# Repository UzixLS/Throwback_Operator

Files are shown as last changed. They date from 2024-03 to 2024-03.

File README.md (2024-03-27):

# THROWBACK OPERATOR
OPL3 VGM player powered by STM32

This project is a hardware video game music (VGM) player that uses a genuine YMF262 (OPL3) sound chip and its accompanying YAC512 DAC.
There is no emulation here. This is the real chip.

Included in this repository is the complete schematic, firmware source, and KiCAD board files. Feel free to make your own board, but please don't resell them :)

If you would like to purchase an official complete Throwback Operator board, you can order one from me here: https://www.aidanlawrence.com/product/throwback-operator/

# Information About the Main Sound Chips and VGM

The YMF262, also known as the Operator Type L3 (OPL3), is an 18-channel FM sound chip that was commonly found inside of personal computers in the mid to late 1990's.
Most notably, the OPL3 was found on the Sound Blaster Pro 2 and the Sound Blaster 16.
The OPL3 is backwards compatible with the OPL2 (YM3812). The OPL2 is backwards compatible with the original OPL (YM3526).
This means that the Throwback Operator is capable of playing back OPL3, OPL2, and OPL tracks. The OPL2 was found on the original Adlib and Sound Blaster cards.
The OPL was usually found within arcade machines.

The clock signal for the YMF262 is dynamically generated from the microcontroller. The timers on this particular board only have 16-bit resolution, so VGMs with exotic frequencies may not sound perfectly in tune. Standard clock OPL2 and OPL3 VGMs will often sound just fine though.

VGM stands for Video Game Music, and it is a 44.1KHz logging format that stores real sound chip register information. My player will parse these files and send the data to the appropriate chips. You can learn more about the VGM file format here: http://www.smspower.org/Music/VGMFileFormat

http://www.smspower.org/uploads/Music/vgmspec170.txt?sid=58da937e68300c059412b536d4db2ca0

# Schematic
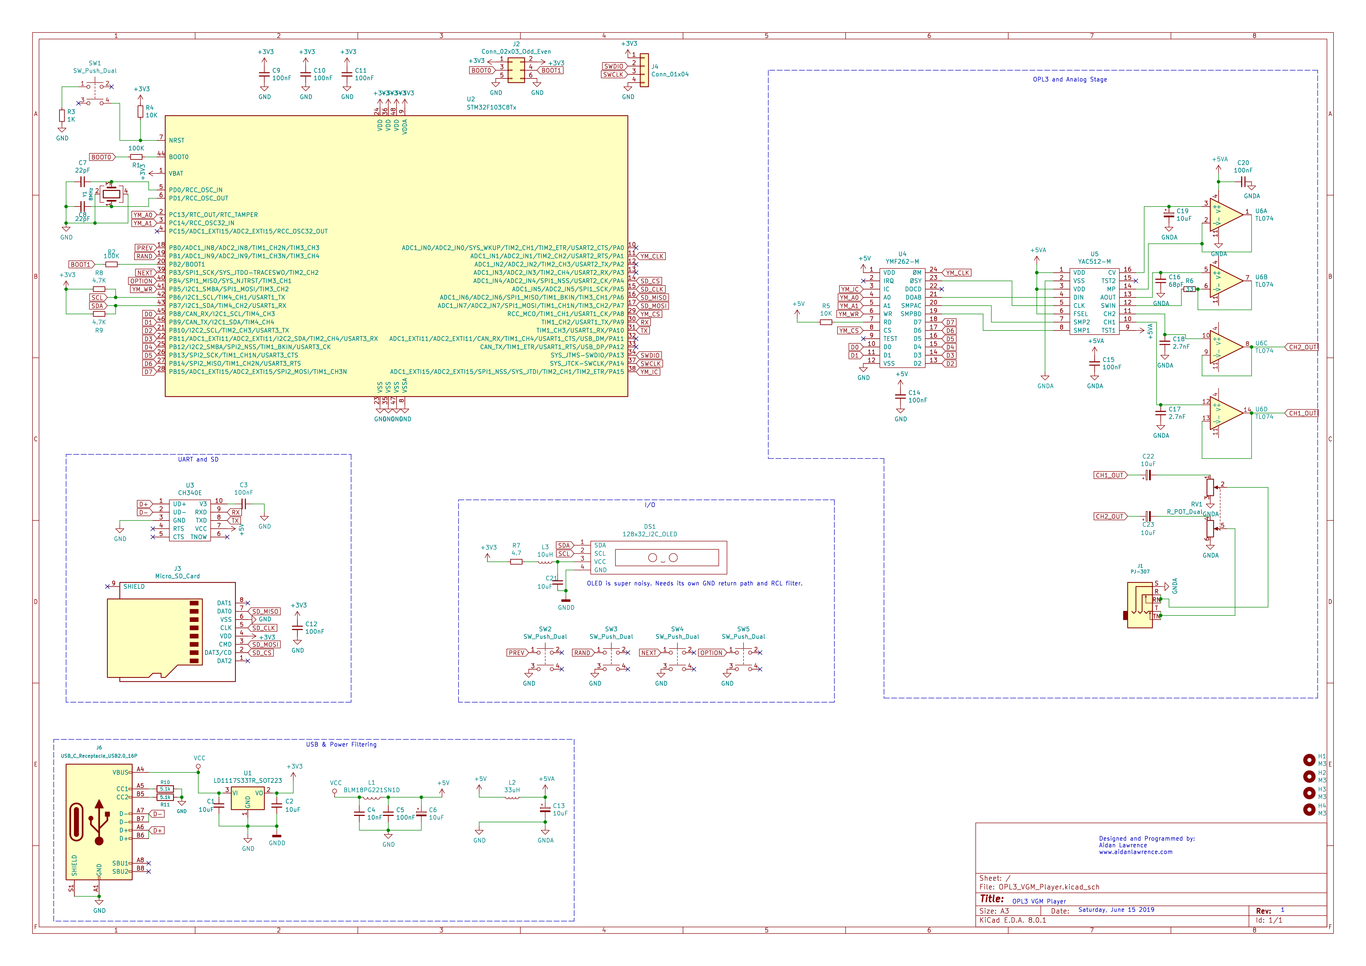
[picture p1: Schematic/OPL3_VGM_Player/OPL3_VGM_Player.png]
Schematic


# SD Card Information

The Throwback Operator accepts MicroSD cards formatted as FAT32. Your SD card must only contain uncompressed .vgm files. VGZ FILES WILL NOT WORK! You may download .vgz files and use 7zip to extract the uncompressed file out of them. Vgm files on the SD card do not need to have the .vgm extension. As long as they contain valid, uncompressed vgm data, they will be read by the program regardless of their name. You can find VGM files by Googling "myGameName VGM," or by checking out sites like http://vgmrips.net/packs/

# Control Over Serial
You can use a serial connection to control playback features. The commands are as follows:

Command | Result
------------ | -------------
\+ | Next Track
\- | Previous Track
\* | Random Track
\/ | Toggle Shuffle Mode
\. | Toggle Song Looping
r: | Request song
? | What song is playing?
\! | Toggle the OLED display

A song request is formatted as follows: ```r:mySongFile.vgm```
Once a song request is sent through the serial console, an attempt will be made to open that song file. The file must exist on the SD card, and spelling/capitalization must be correct.
Need an easy-to-use serial console? [I've made one here.](https://github.com/AidanHockey5/OpenArduinoSerialConsole)

# Programming the Microcontroller

The on-board microcontroller is a STM32F103C8T6, the same microcontroller found on the popular "blue pill" development boards. 
Therefore, programming the Throwback Operator boards is fairly similar.
The firmware was built with Visual Studio Code with the PlatformIO extension installed.

Programming over Serial:
* Connect your Throwback Operator board to your computers USB port.
* Ensure that you have the CH340 driver installed. Windows 10 should have this automatically, otherwise, [grab the driver here](https://sparks.gogo.co.nz/ch340.html)
* Ensure nothing else is currently connected to your board over serial.
* On the top of the board, you will see two black jumpers. By default, these jumpers are both in the "Down" position (middle pin and bottom pin jumped).
* Remove the left jumper and reattach it to the "Up" position (middle pin and top pin jumped).
* Press the RESET button on the Throwback Operator board

* You can either program the device with the flashing tool linked below, or from the source code.

[DOWNLOAD THE FLASHING TOOL HERE](https://www.aidanlawrence.com/tools/ee/tbo/Megaflasher_Throwback_Operator.zip)

* Windows users are reccomended to run the pre-compiled "Flash.exe" file.
  All other operating system users must run the Flash.py file. 
  Dependancies and instructions are listed in the Readme file.
* After successfully running the flashing tool, you are done and don't need to continue with the following instructions.

If you plan to build from the source code instead:
* In VS Code (or whatever your IDE of choice is), navigate to the `platformio.ini` and ensure the upload protocol is set to `serial`
* Hit the upload button (Arrow icon in the bottom bar of VS code)
* Once your code is uploaded, replace the left jumper to its original "Down" position 

# Troubleshooting

Occasionally, when the player is first plugged in, it will hang or get caught in a boot-loop. Plugging in a USB cable gives breif moments of unstable power when the contacts inside of the connector are jostling against eachother which may place the SD card in an unknown state. Simply disconnect and reconnect the USB cable if you are caught in a bootloop.

This player is for OPL-family VGMs only. That means you can play any VGM file that contains data for the YM3526 (OPL), YM3812 (OPL2) or the YMF262 (OPL3).

Ensure that your VGM files are uncompressed. VGZ files will not work. Simply use 7zip on VGM files to extract the VGM files within.

Make sure your SD card is formatted to FAT32 and only contains VGM files. Folders are not supported.

# Looking for an Enclosure for your Player?

Voodle has contributed a 3D-printable enclosure for the Throwback Operator!
https://www.thingiverse.com/thing:4577831

Thanks, Voodle!

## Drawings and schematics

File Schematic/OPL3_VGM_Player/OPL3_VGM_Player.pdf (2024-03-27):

# 100nF ⁺³V³

# +5VA GNDA

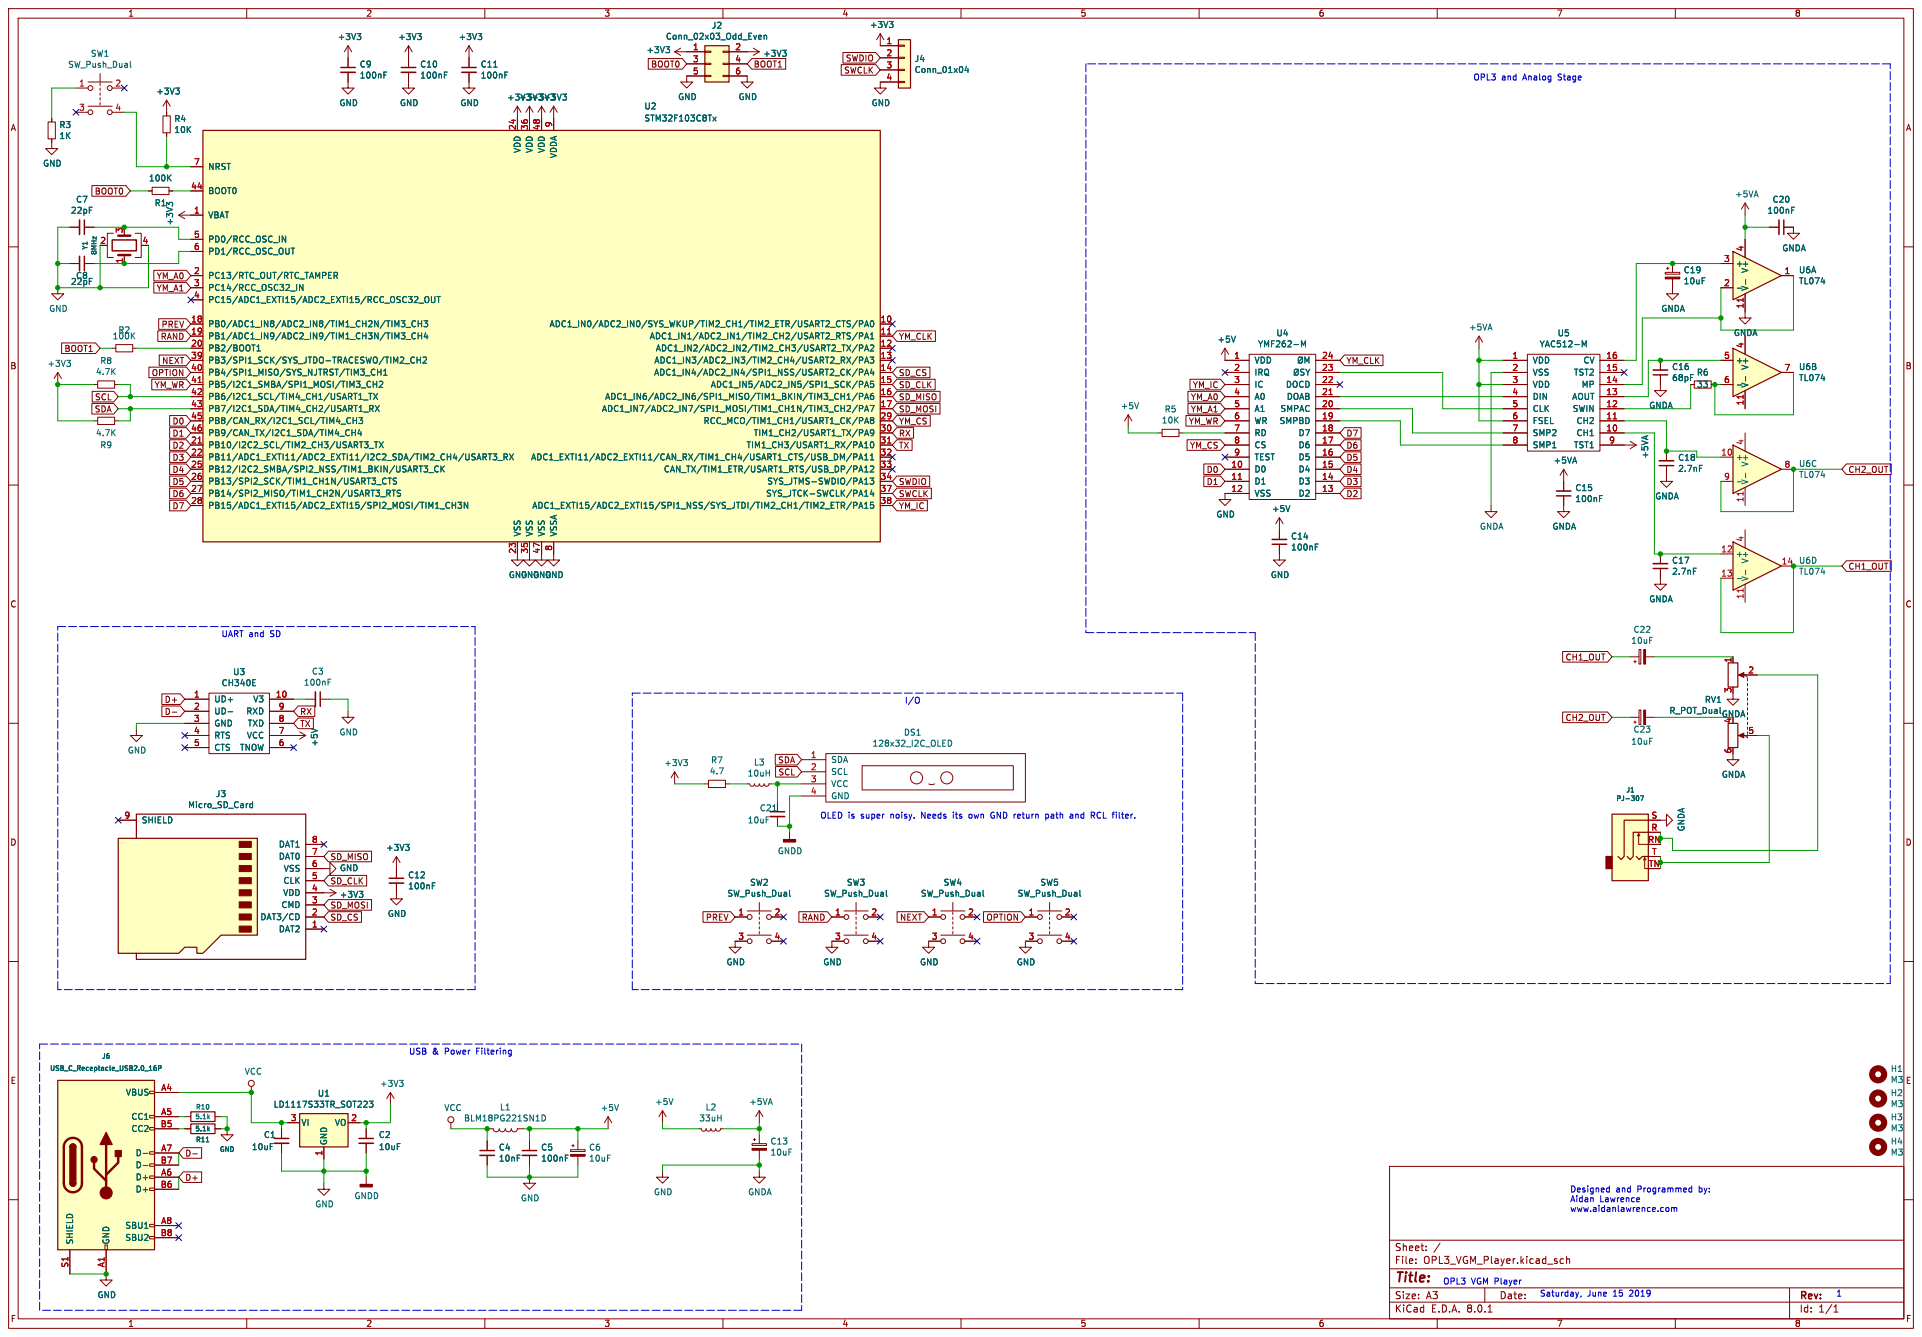
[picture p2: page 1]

Id: 1/1 Title: File: OPL3_VGM_Player.kicad_sch Sheet: /

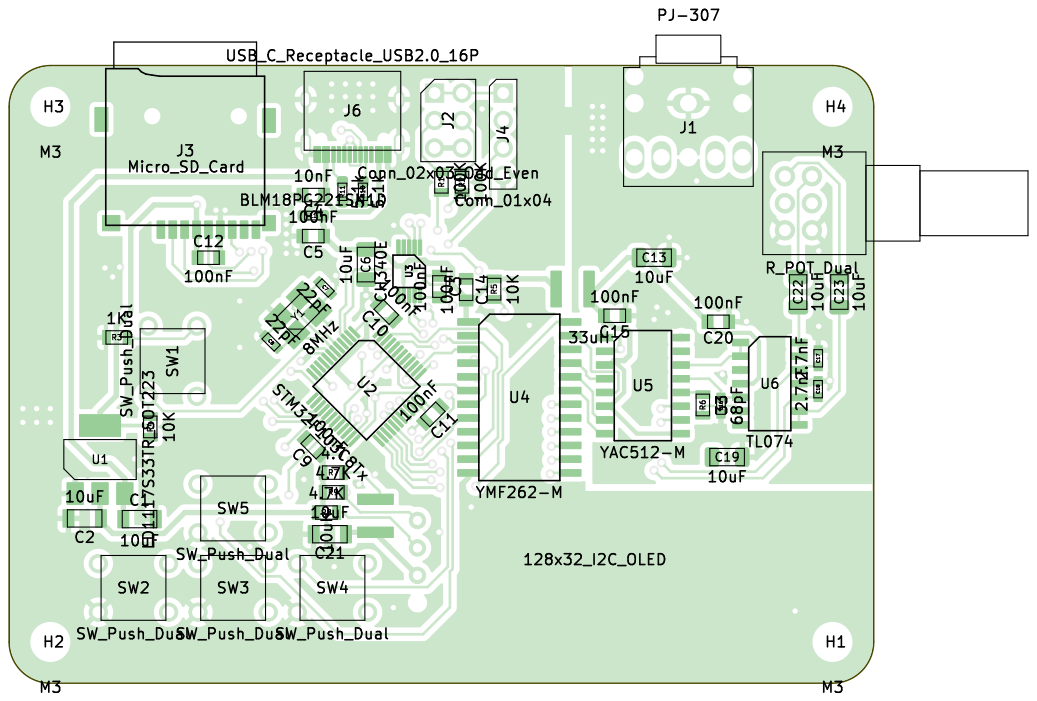
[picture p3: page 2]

Id: 1/1 Title: File: OPL3_VGM_Player.kicad_pcb Sheet:

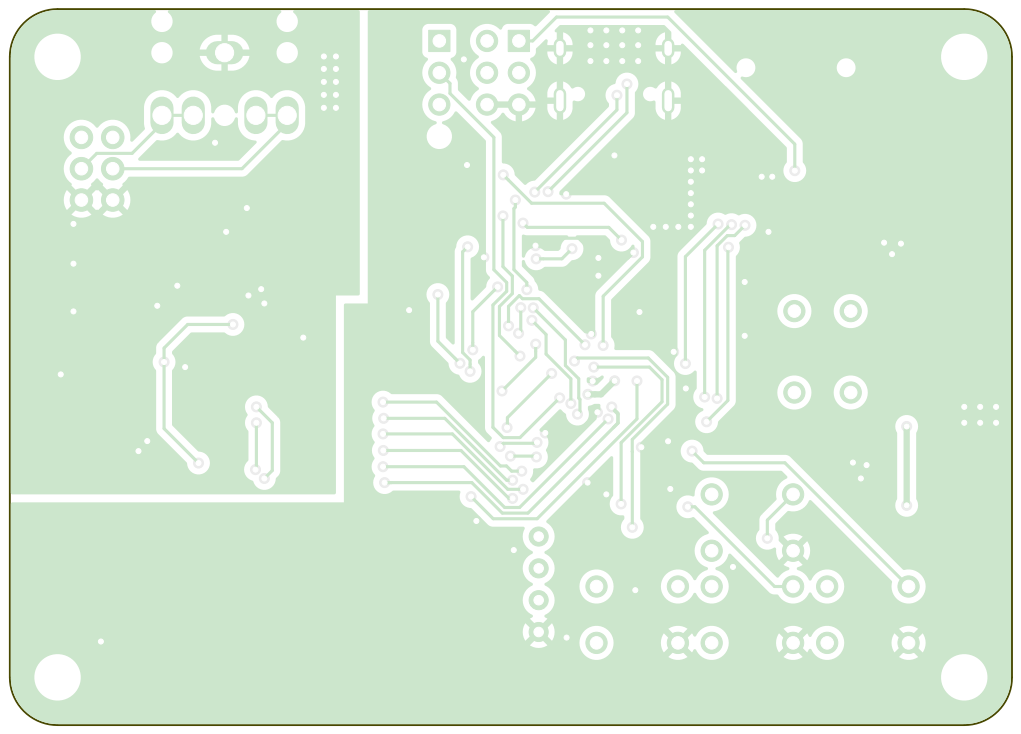
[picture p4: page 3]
D Date: KiCad; E.D.A. 8.0.1 Size: A4; Rev:

Id: 1/1 Title: File: OPL3_VGM_Player.kicad_pcb Sheet:

# Bill Of Materials

References | | | Value | Footprint | Qty
C1 C2 C21 | 10uF | Capacitors_SMD:C_1206 | 3
C3 C5 C9 C10 C11 C12 C14 C15 C20 | 100nF | Capacitors_SMD:C_0805 | 9
C4 | 10nF | Capacitors_SMD:C_0805 | 1
C6 C13 C19 C22 C23 | 10uF | Capacitor_SMD:C_1206_3216Metric | 5
C7 C8 | 22pF | Capacitors_SMD:C_0603 | 2
C16 | 68pF | Capacitors_SMD:C_0603 | 1
C17 C18 | 2.7nF | Capacitors_SMD:C_0603 | 2
DS1 | 128x32_I2C_OLED | oled_display:128x32_OLED_I2C_Module | 1
H1 H2 H3 H4 | M3 | Mounting_Holes:MountingHole_3.2mm_M3 | 4
J1 | PJ-307 | my:PJ-307 | 1
J2 | Conn_02x03_Odd_Even | Pin_Headers:Pin_Header_Straight_2x03_Pit ch2.54mm | 1
J3 | Micro_SD_Card | my:GCT-MEM2055-00-190-01-A | 1
J4 | Conn_01x04 | Pin_Headers:Pin_Header_Straight_1x04_Pit ch2.54mm | 1
J6 | USB_C_Receptacle_USB2.0_16P | Connector_USB:USB_C_Receptacle_HRO_ TYPE-C-31-M-12 | 1
L1 | BLM18PG221SN1D | Inductor_SMD:L_0603_1608Metric_Pad1.05 x0.95mm_HandSolder | 1
L2 | 33uH | custom_inductors:L_4x4 | 1
L3 | 10uH | custom_inductors:L_4x4 | 1
R1 R2 | 100K | Resistors_SMD:R_0805 | 2
R3 | 1K | Resistors_SMD:R_0805 | 1
R4 R5 | 10K | Resistors_SMD:R_0805 | 2
R6 | 33 | Resistors_SMD:R_0805 | 1
R7 | 4.7 | Resistors_SMD:R_0805 | 1
R8 R9 | 4.7K | Resistors_SMD:R_0805 | 2
R10 R11 | 5.1k | Resistor_SMD:R_0603_1608Metric_Pad0.98 x0.95mm_HandSolder | 2
RV1 | R_POT_Dual | Potentiometers:Potentiometer_Alps_RK097_ Double_Vertical | 1
SW1 SW2 SW3 SW4 SW5 | SW_Push_Dual | Buttons_Switches_THT:SW_TH_Tactile_Omr on_B3F-10xx | 5
U1 | LD1117S33TR_SOT223 | TO_SOT_Packages_SMD:SOT-223-3_TabPi n2 | 1
U2 | STM32F103C8Tx | Housings_QFP:LQFP-48_7x7mm_Pitch0.5m m | 1
U3 | CH340E | Housings_SSOP:MSOP-10_3x3mm_Pitch0.5 mm | 1
U4 | YMF262-M | Housings_SOIC:SOIC-24W_7.5x15.4mm_Pit ch1.27mm | 1
U5 | YAC512-M | Housings_SOIC:SOIC-16W_5.3x10.2mm_Pit ch1.27mm | 1

# OPL3_VGM_Player rev. BOM page 1/2

U6 | TL074 | Housings_SOIC:SOIC-14_3.9x8.7mm_Pitch1 .27mm | 1
Y1 | 8MHz | Crystal:Crystal_SMD_SeikoEpson_TSX3225-4Pin_3.2x2.5mm_HandSoldering | 1

# OPL3_VGM_Player rev. BOM page 2/2

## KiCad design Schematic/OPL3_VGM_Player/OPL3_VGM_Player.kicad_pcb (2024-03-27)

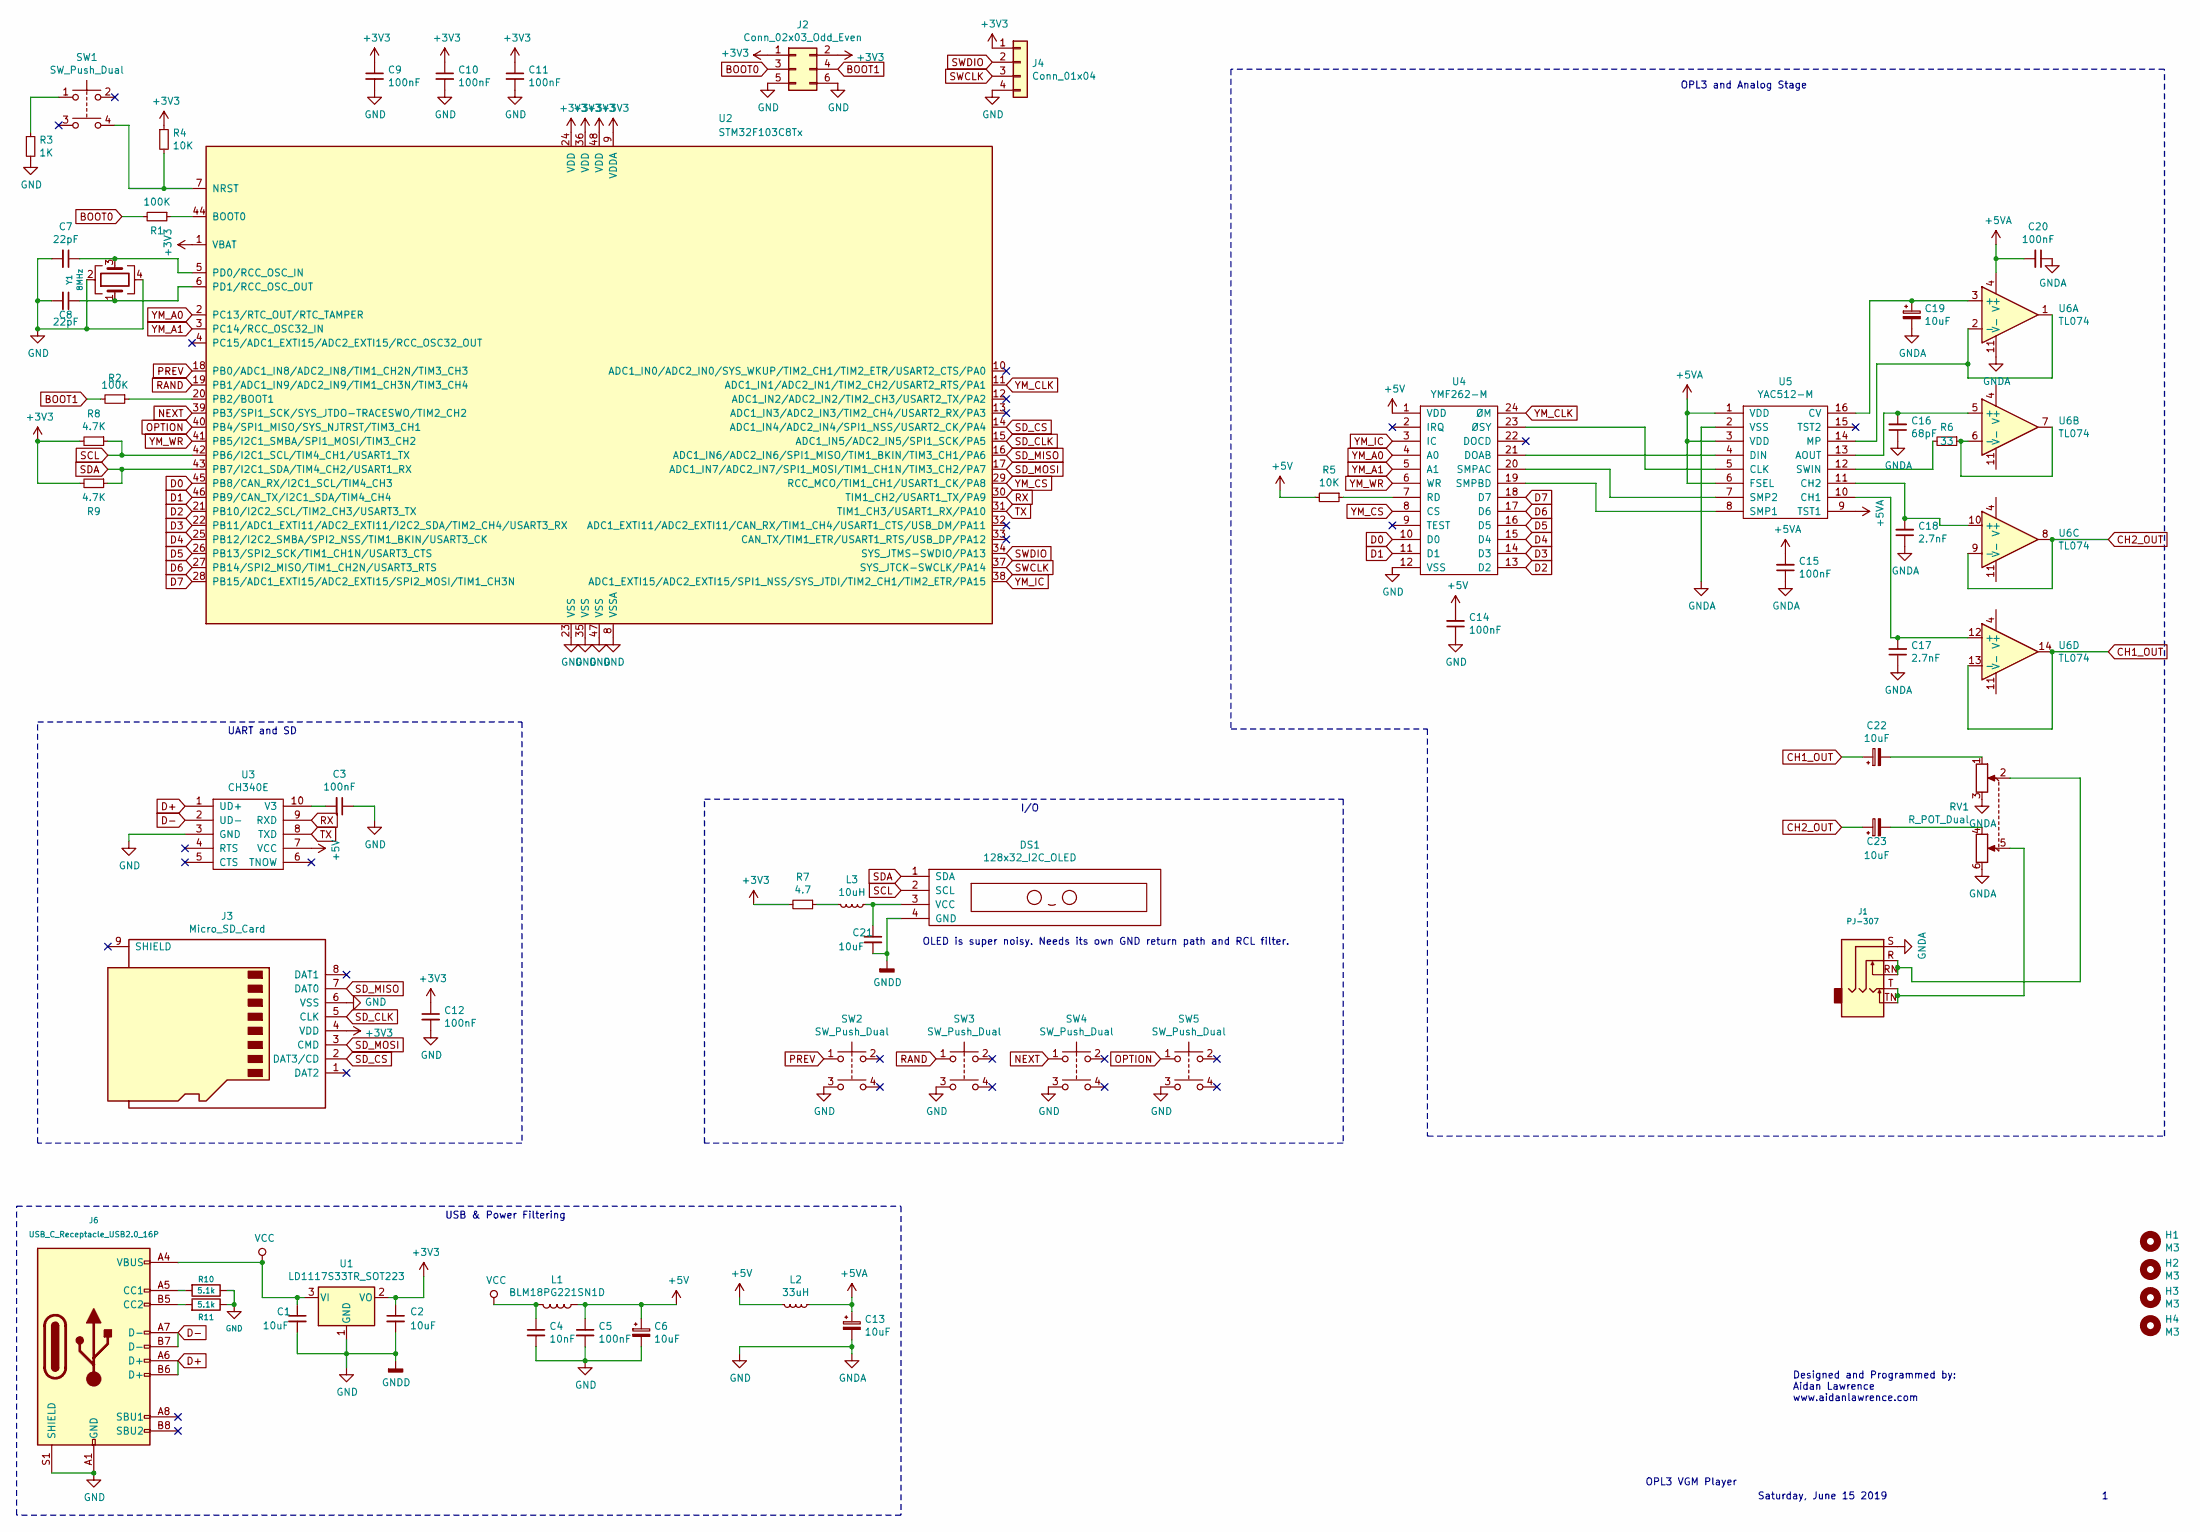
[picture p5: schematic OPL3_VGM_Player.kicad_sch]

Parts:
C1, C2, C21: 10uF; C_1206
C3, C5, C9, C10, C11, C12, C14, C15, C20: 100nF; C_0805
C4: 10nF; C_0805
C6, C13, C19, C22, C23: 10uF; C_1206_3216Metric
C7, C8: 22pF; C_0603
C16: 68pF; C_0603
C17, C18: 2.7nF; C_0603
DS1: 128x32_I2C_OLED; 128x32_OLED_I2C_Module
H1, H2, H3, H4: M3; MountingHole_3.2mm_M3
J1: PJ-307
J2: Conn_02x03_Odd_Even; Pin_Header_Straight_2x03_Pitch2.54mm
J3: Micro_SD_Card; GCT-MEM2055-00-190-01-A
J4: Conn_01x04; Pin_Header_Straight_1x04_Pitch2.54mm
J6: USB_C_Receptacle_USB2.0_16P; USB_C_Receptacle_HRO_TYPE-C-31-M-12
L1: BLM18PG221SN1D; L_0603_1608Metric_Pad1.05x0.95mm_HandSolder
L2: 33uH; L_4x4
L3: 10uH; L_4x4
R1, R2: 100K; R_0805
R3: 1K; R_0805
R4, R5: 10K; R_0805
R6: 33; R_0805
R7: 4.7; R_0805
R8, R9: 4.7K; R_0805
R10, R11: 5.1k; R_0603_1608Metric_Pad0.98x0.95mm_HandSolder
RV1: R_POT_Dual; Potentiometer_Alps_RK097_Double_Vertical
SW1, SW2, SW3, SW4, SW5: SW_Push_Dual; SW_TH_Tactile_Omron_B3F-10xx
U1: LD1117S33TR_SOT223; SOT-223-3_TabPin2
U2: STM32F103C8Tx; LQFP-48_7x7mm_Pitch0.5mm
U3: CH340E; MSOP-10_3x3mm_Pitch0.5mm
U4: YMF262-M; SOIC-24W_7.5x15.4mm_Pitch1.27mm
U5: YAC512-M; SOIC-16W_5.3x10.2mm_Pitch1.27mm
U6: TL074; SOIC-14_3.9x8.7mm_Pitch1.27mm
Y1: 8MHz; Crystal_SMD_SeikoEpson_TSX3225-4Pin_3.2x2.5mm_HandSoldering

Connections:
+3V3: C2.1, C9.1, C10.1, C11.1, C12.1, J2.1, J2.2, J3.4 (VDD), J4.1, R4.1, R7.2, R8.2, R9.2, U1.2 (VO), U2.1 (VBAT), U2.9 (VDDA), U2.24 (VDD), U2.36 (VDD), U2.48 (VDD)
+5V: C5.1, C6.1, C14.2, L1.1, L2.2, R5.2, U3.7 (VCC), U4.1 (VDD)
+5VA: C13.1, C15.2, C20.2, L2.1, U5.1 (VDD), U5.3 (VDD), U5.6 (FSEL), U5.9 (TST1), U6.4 (V+)
BOOT0: J2.3, R1.2
BOOT1: J2.4, R2.2
CH1_OUT: C22.1, U6.13 (-), U6.14
CH2_OUT: C23.1, U6.8, U6.9 (-)
D0: U2.45 (PB8/CAN_RX/I2C1_SCL/TIM4_CH3), U4.10 (D0)
D1: U2.46 (PB9/CAN_TX/I2C1_SDA/TIM4_CH4), U4.11 (D1)
D2: U2.21 (PB10/I2C2_SCL/TIM2_CH3/USART3_TX), U4.13 (D2)
D3: U2.22 (PB11/ADC1_EXTI11/ADC2_EXTI11/I2C2_SDA/T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), U4.14 (D3)
D4: U2.25 (PB12/I2C2_SMBA/SPI2_NSS/TIM1_BKIN/USART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), U4.15 (D4)
D5: U2.26 (PB13/SPI2_SCK/TIM1_CH1N/USART3_CTS), U4.16 (D5)
D6: U2.27 (PB14/SPI2_MISO/TIM1_CH2N/USART3_RTS), U4.17 (D6)
D7: U2.28 (PB15/ADC1_EXTI15/ADC2_EXTI15/SPI2_MOSI/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), U4.18 (D7)
D+: J6.A6 (D+), J6.B6 (D+), U3.1 (UD+)
D-: J6.A7 (D-), J6.B7 (D-), U3.2 (UD-)
GND: C1.2, C2.2, C3.1, C4.2, C5.2, C6.2, C7.2, C8.2, C9.2, C10.2, C11.2, C12.2, C13.2, C14.1, C15.1, C16.1, C17.1, C18.1, C19.2, C20.1, C21.2, DS1.4 (GND), J1.S, J2.5, J2.6, J3.6 (VSS), J4.4, J6.A1 (GND), J6.A12 (GND), J6.B1 (GND), J6.B12 (GND), J6.S1 (SHIELD), R3.2, R10.1, R11.1, RV1.3, RV1.6, SW2.3, SW3.3, SW4.3, SW5.3, U1.1 (GND), U2.8 (VSSA), U2.23 (VSS), U2.35 (VSS), U2.47 (VSS), U3.3 (GND), U4.12 (VSS), U5.2 (VSS), U6.11 (V-), Y1.2, Y1.4
NEXT: SW4.1, U2.39 (PB3/SPI1_SCK/SYS_JTDO-TRACESWO/TIM2_CH2)
unnamed: C22.2, RV1.1
unnamed: C23.2, RV1.4
unnamed: C21.1, DS1.3 (VCC), L3.1
unnamed: J1.R, J1.RN, RV1.2
unnamed: J1.T, J1.TN, RV1.5
unnamed: J6.A5 (CC1), R10.2
unnamed: J6.B5 (CC2), R11.2
unnamed: L3.2, R7.1
unnamed: R3.1, SW1.1
unnamed: R1.1, U2.44 (BOOT0)
unnamed: R4.2, SW1.4, U2.7 (NRST)
unnamed: R2.1, U2.20 (PB2/BOOT1)
unnamed: C7.1, U2.5 (PD0/RCC_OSC_IN), Y1.3
unnamed: C8.1, U2.6 (PD1/RCC_OSC_OUT), Y1.1
unnamed: C3.2, U3.10 (V3)
unnamed: U4.21 (DOAB), U5.4 (DIN)
unnamed: R5.1, U4.7 (RD)
unnamed: U4.20 (SMPAC), U5.7 (SMP2)
unnamed: U4.19 (SMPBD), U5.8 (SMP1)
unnamed: U4.23 (ØSY), U5.5 (CLK)
unnamed: C16.2, U5.13 (AOUT), U6.5 (+)
unnamed: C17.2, U5.10 (CH1), U6.12 (+)
unnamed: C18.2, U5.11 (CH2), U6.10 (+)
unnamed: C19.1, U5.16 (CV), U6.3 (+)
unnamed: U5.14 (MP), U6.1, U6.2 (-)
unnamed: R6.2, U5.12 (SWIN)
unnamed: R6.1, U6.6 (-), U6.7
OPTION: SW5.1, U2.40 (PB4/SPI1_MISO/SYS_NJTRST/TIM3_CH1)
PREV: SW2.1, U2.18 (PB0/ADC1_IN8/ADC2_IN8/TIM1_CH2N/TIM3_CH3)
RAND: SW3.1, U2.19 (PB1/ADC1_IN9/ADC2_IN9/TIM1_CH3N/TIM3_CH4)
RX: U2.30 (TIM1_CH2/USART1_TX/PA9), U3.9 (RXD)
SCL: DS1.2 (SCL), R8.1, U2.42 (PB6/I2C1_SCL/TIM4_CH1/USART1_TX)
SDA: DS1.1 (SDA), R9.1, U2.43 (PB7/I2C1_SDA/TIM4_CH2/USART1_RX)
SD_CLK: J3.5 (CLK), U2.15 (ADC1_IN5/ADC2_IN5/SPI1_SCK/PA5)
SD_CS: J3.2 (DAT3/CD), U2.14 (ADC1_IN4/ADC2_IN4/SPI1_NSS/USART2_CK/PA4)
SD_MISO: J3.7 (DAT0), U2.16 (ADC1_IN6/ADC2_IN6/SPI1_MISO/TIM1_BKIN/T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)
SD_MOSI: J3.3 (CMD), U2.17 (ADC1_IN7/ADC2_IN7/SPI1_MOSI/TIM1_CH1N/T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)
SWCLK: J4.3, U2.37 (SYS_JTCK-SWCLK/PA14)
SWDIO: J4.2, U2.34 (SYS_JTMS-SWDIO/PA13)
TX: U2.31 (TIM1_CH3/USART1_RX/PA10), U3.8 (TXD)
VCC: C1.1, C4.1, J6.A4 (VBUS), J6.A9 (VBUS), J6.B4 (VBUS), J6.B9 (VBUS), L1.2, U1.3 (VI)
YM_A0: U2.2 (PC13/RTC_OUT/RTC_TAMPER), U4.4 (A0)
YM_A1: U2.3 (PC14/RCC_OSC32_IN), U4.5 (A1)
YM_CLK: U2.11 (ADC1_IN1/ADC2_IN1/TIM2_CH2/USART2_RTS/P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), U4.24 (ØM)
YM_CS: U2.29 (RCC_MCO/TIM1_CH1/USART1_CK/PA8), U4.8 (CS)
YM_IC: U2.38 (ADC1_EXTI15/ADC2_EXTI15/SPI1_NSS/SYS_JT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), U4.3 (IC)
YM_WR: U2.41 (PB5/I2C1_SMBA/SPI1_MOSI/TIM3_CH2), U4.6 (WR)

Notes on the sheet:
OPL3 and Analog Stage
Saturday, June 15 2019
OPL3 VGM Player
Designed and Programmed by: Aidan Lawrence www.aidanlawrence.com
I/O
USB & Power Filtering
UART and SD
OLED is super noisy. Needs its own GND return path and RCL filter.

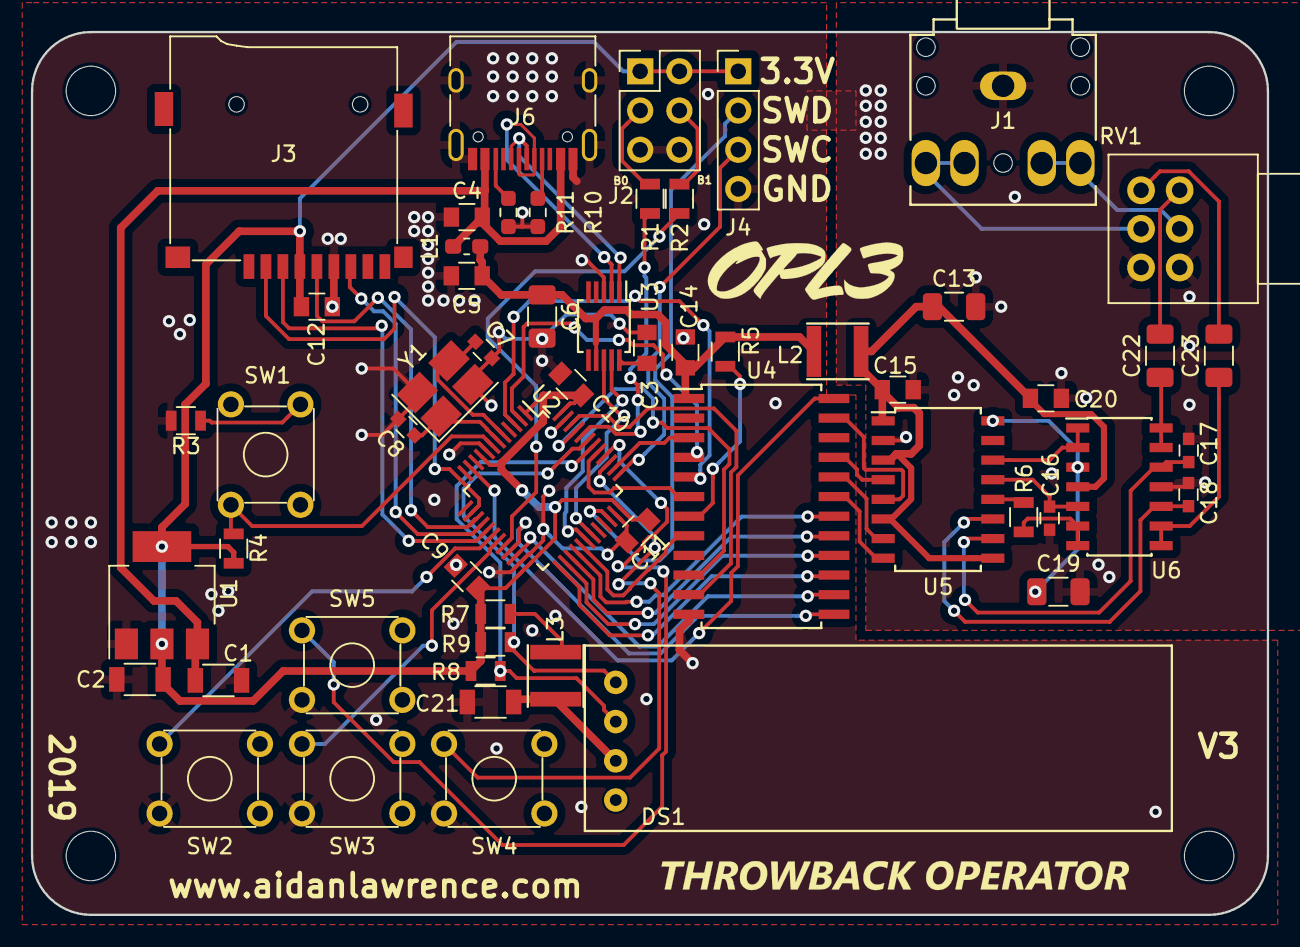
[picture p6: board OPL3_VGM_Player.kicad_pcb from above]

Board: 2 copper layers, 80.0 x 57.2 mm, 60 parts (0 on the bottom side), 66 nets.
